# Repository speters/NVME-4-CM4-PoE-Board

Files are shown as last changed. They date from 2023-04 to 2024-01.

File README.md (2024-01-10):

# CM4-IO-POE-4G PCIEx1 to NVME Adapter

This is an NVME (M-key) adapter board for the PCIEx1 slot.

Its PCB is designed with a break-away section for the fingered connector. This is then soldered in a matching slot of the PCB to form a 90 degree connector.

## Revisions

 * 0.9.0 added oscillator for 32.768kHz SUSClk signal

 * 0.8.2 finger board improvements, minor size adjustments

 * 0.8.1 working version, gone into small production run

## Description

PCB of the 0.8.2 version without SUSClk
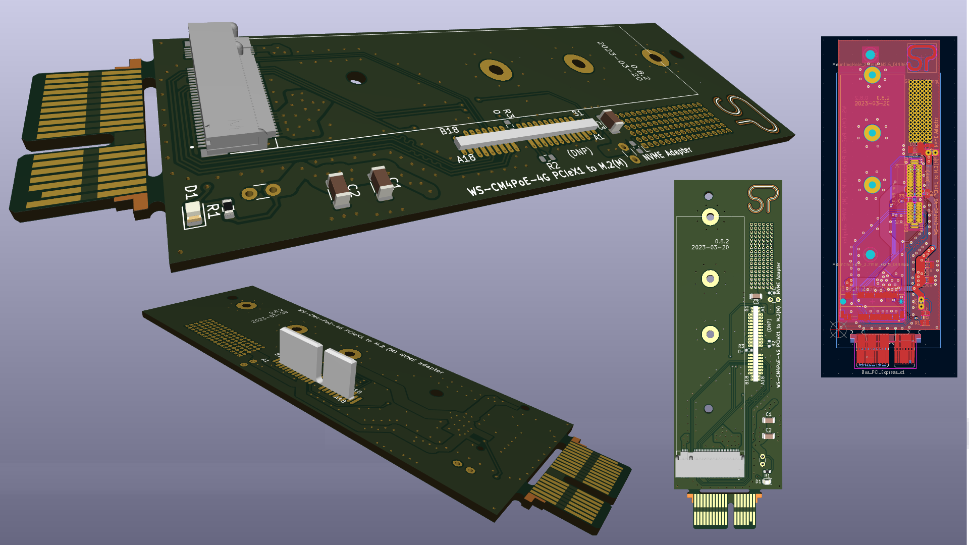
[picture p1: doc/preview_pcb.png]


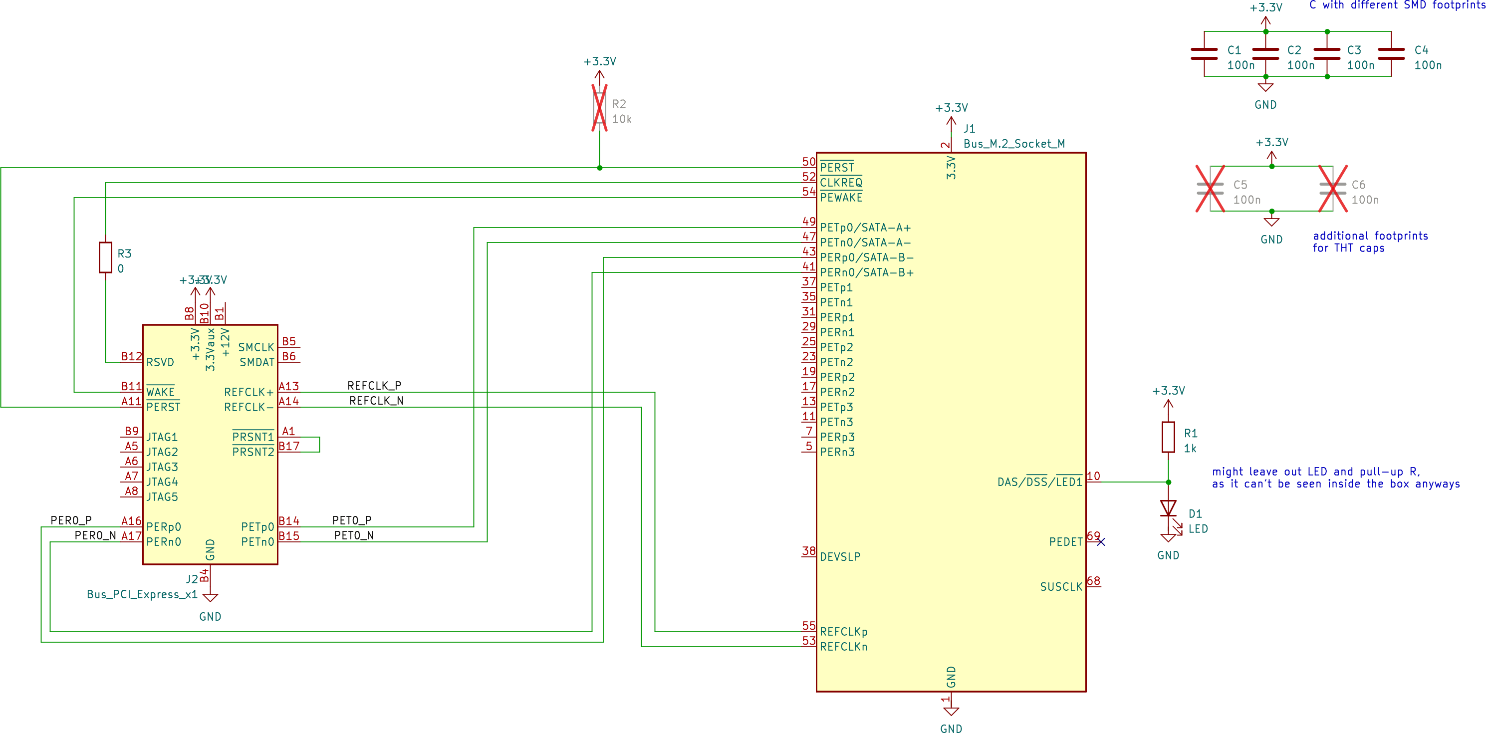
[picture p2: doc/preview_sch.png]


It is designed to fit the [Waveshare CM4G-IO-POE-4G-BOX](https://www.waveshare.com/wiki/Compute_Module_4_PoE_4G_Board#Isolation_GPIO.2FI2C).

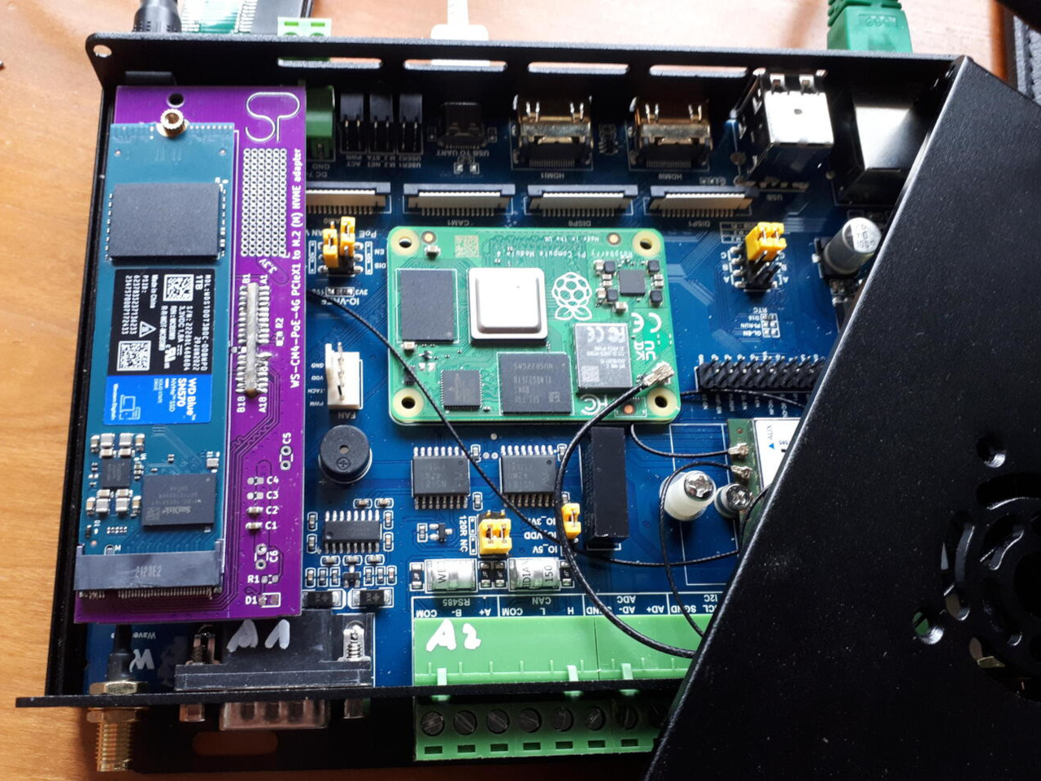
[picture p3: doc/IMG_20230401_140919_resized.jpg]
adapter in use


## Building

The PCB is cost-optimized to be produced by services like JLCPCB.

You have to separate the finger board from the PCB and solder it into its slot.
Make sure the finger board is at right angles to the main PCB when soldering.

An NVME M-key connector, a standoff, and screw for mounting the NVME has to be provided.
It is recommended to fix the board to the CM4 board with standoffs, not rely solely on the PCIEx1 connector to hold everything in place. For doing this, there are two holes matching holes in the baseboard PCB.

The adapter seems to work fine on the CM4 board without fitting the passives (capacitors and LED).

Remember that your kernel needs PCIe support. There is a convenient [docker cross-compile environment by Jeff Geerling](https://github.com/geerlingguy/raspberry-pi-pcie-devices/tree/master/extras/cross-compile).

## Improvement ideas

 * choose gold fingers for production (I went as cheap as possible with HASL)

 * get out of the way for the CAM0 FPC cable

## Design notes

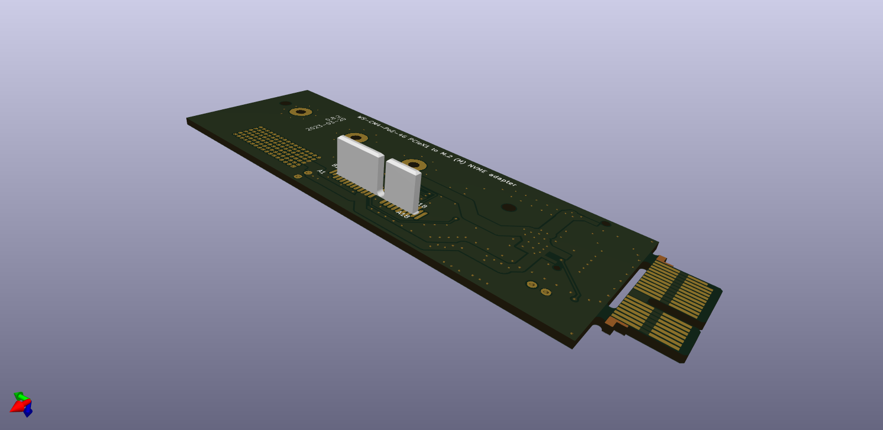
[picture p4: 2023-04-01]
doc/preview_pcb4.png

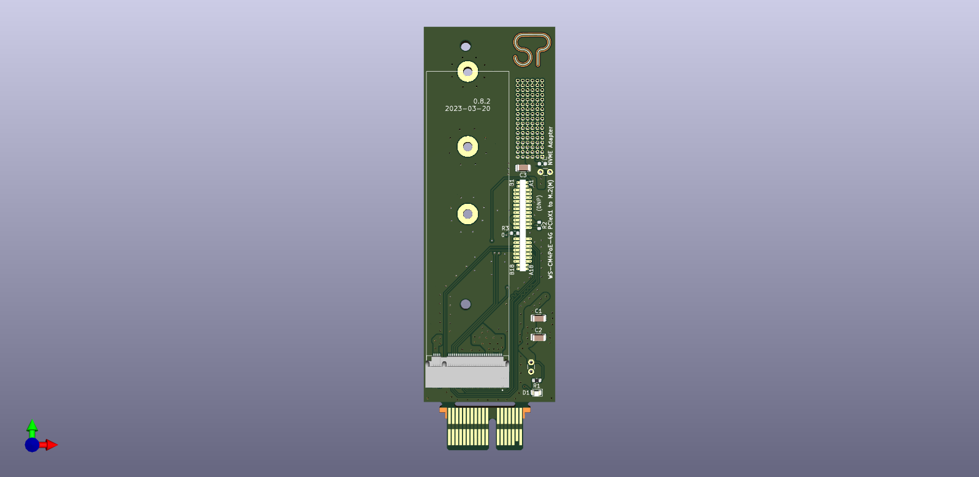
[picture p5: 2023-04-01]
doc/preview_pcb2.png

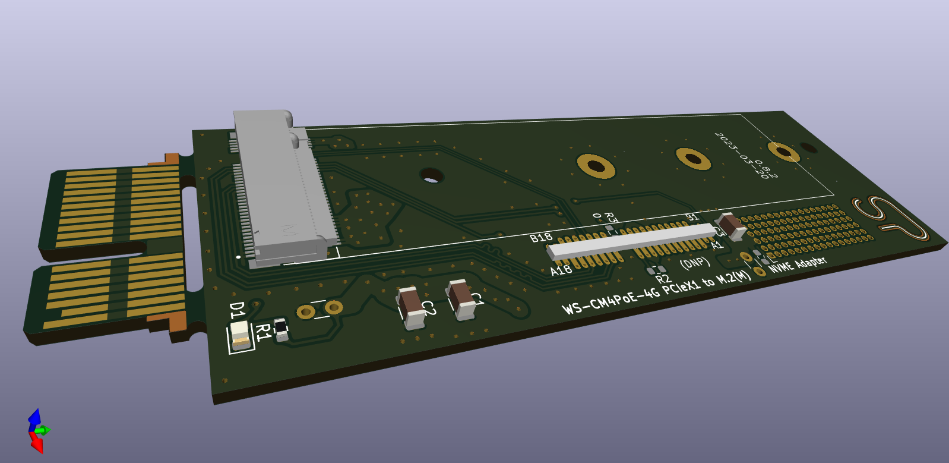
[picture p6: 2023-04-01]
doc/preview_pcb1.png

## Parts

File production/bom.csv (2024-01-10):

Designator | Footprint | Quantity | Value | LCSC Part #
C1 | 1206 | 1 | 100n
C2 | 1206 | 1 | 100n
C3 | 1206 | 1 | 100n
C4 | 0603 | 1 | 100n
C5, C6 | C_Disc_D3.0mm_W1.6mm_P2.50mm | 2 | 100n
C7 | 1206 | 1 | 100n
D1 | 0805 | 1 | LED
J1 | TE_1-2199230-6 M2 2280 | 1 | Bus_M.2_Socket_M
J2 | BUS_PCIexpress_x1 hor_1 | 1 | Bus_PCI_Express_x1
J3 | BUS_PCIexpress_x1 | 1 | Bus_PCI_Express_x1
J4 | BUS_PCIexpress_x1 SOLDER | 1 | Bus_PCI_Express_x1
J5 | proto112 127 | 1 | PROTO6x17
R1 | 0603 | 1 | 1k
R2 | 0603 | 1 | 10k
R3 | 0603 | 1 | 0
X1 | Oscillator_SMD_EuroQuartz_XO32-4Pin_3.2x2.5mm | 1 | 32.768kHz

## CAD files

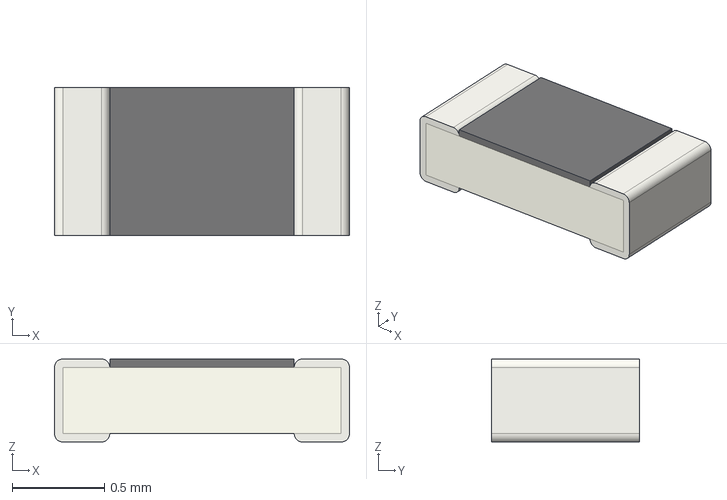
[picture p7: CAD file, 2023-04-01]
3d/R_0603_1608Metric.step
1.60 x 0.8 x 0.45 mm

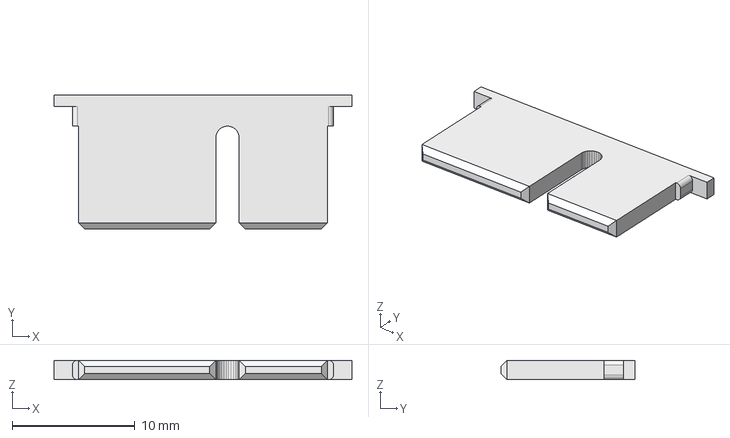
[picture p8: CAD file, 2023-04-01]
fingerconn.FCStd
24.3 x 10.9 x 1.58 mm

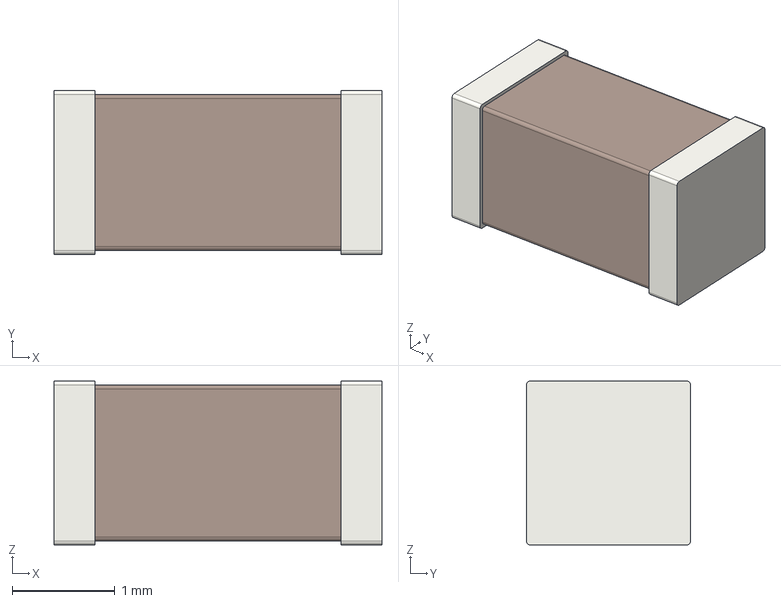
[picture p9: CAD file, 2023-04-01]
3d/C_1206_3216Metric.step
3.20 x 1.60 x 1.60 mm

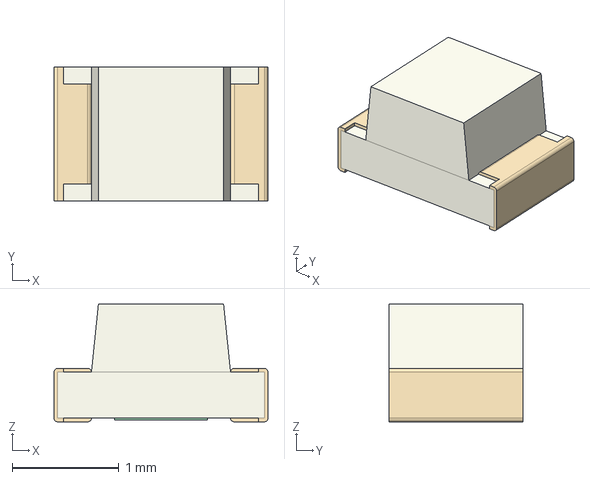
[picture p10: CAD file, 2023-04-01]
3d/LED_0805_2012Metric.step
2.00 x 1.25 x 1.10 mm

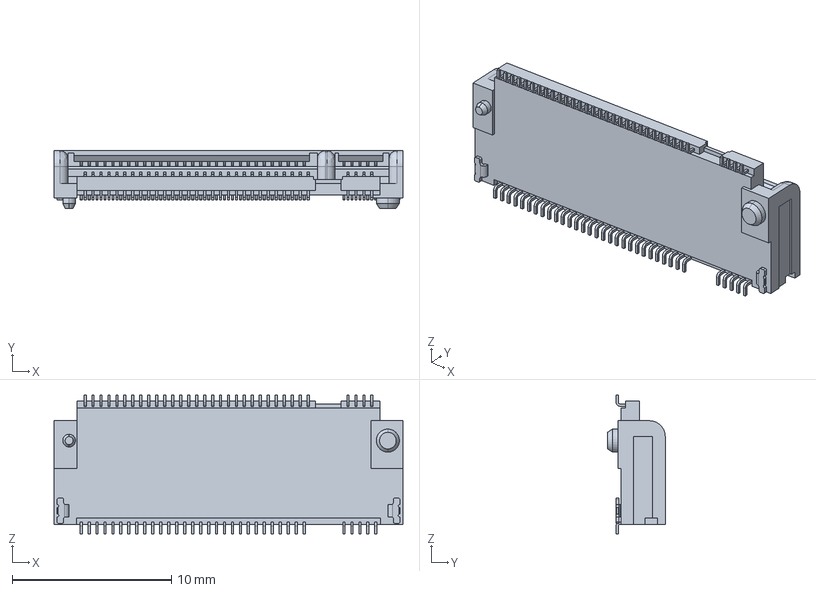
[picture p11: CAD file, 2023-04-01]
3d/c-1-2199119-3-c-3d.stp
21.9 x 3.62 x 8.70 mm

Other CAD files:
3d/fingerconn-fingerconn.step

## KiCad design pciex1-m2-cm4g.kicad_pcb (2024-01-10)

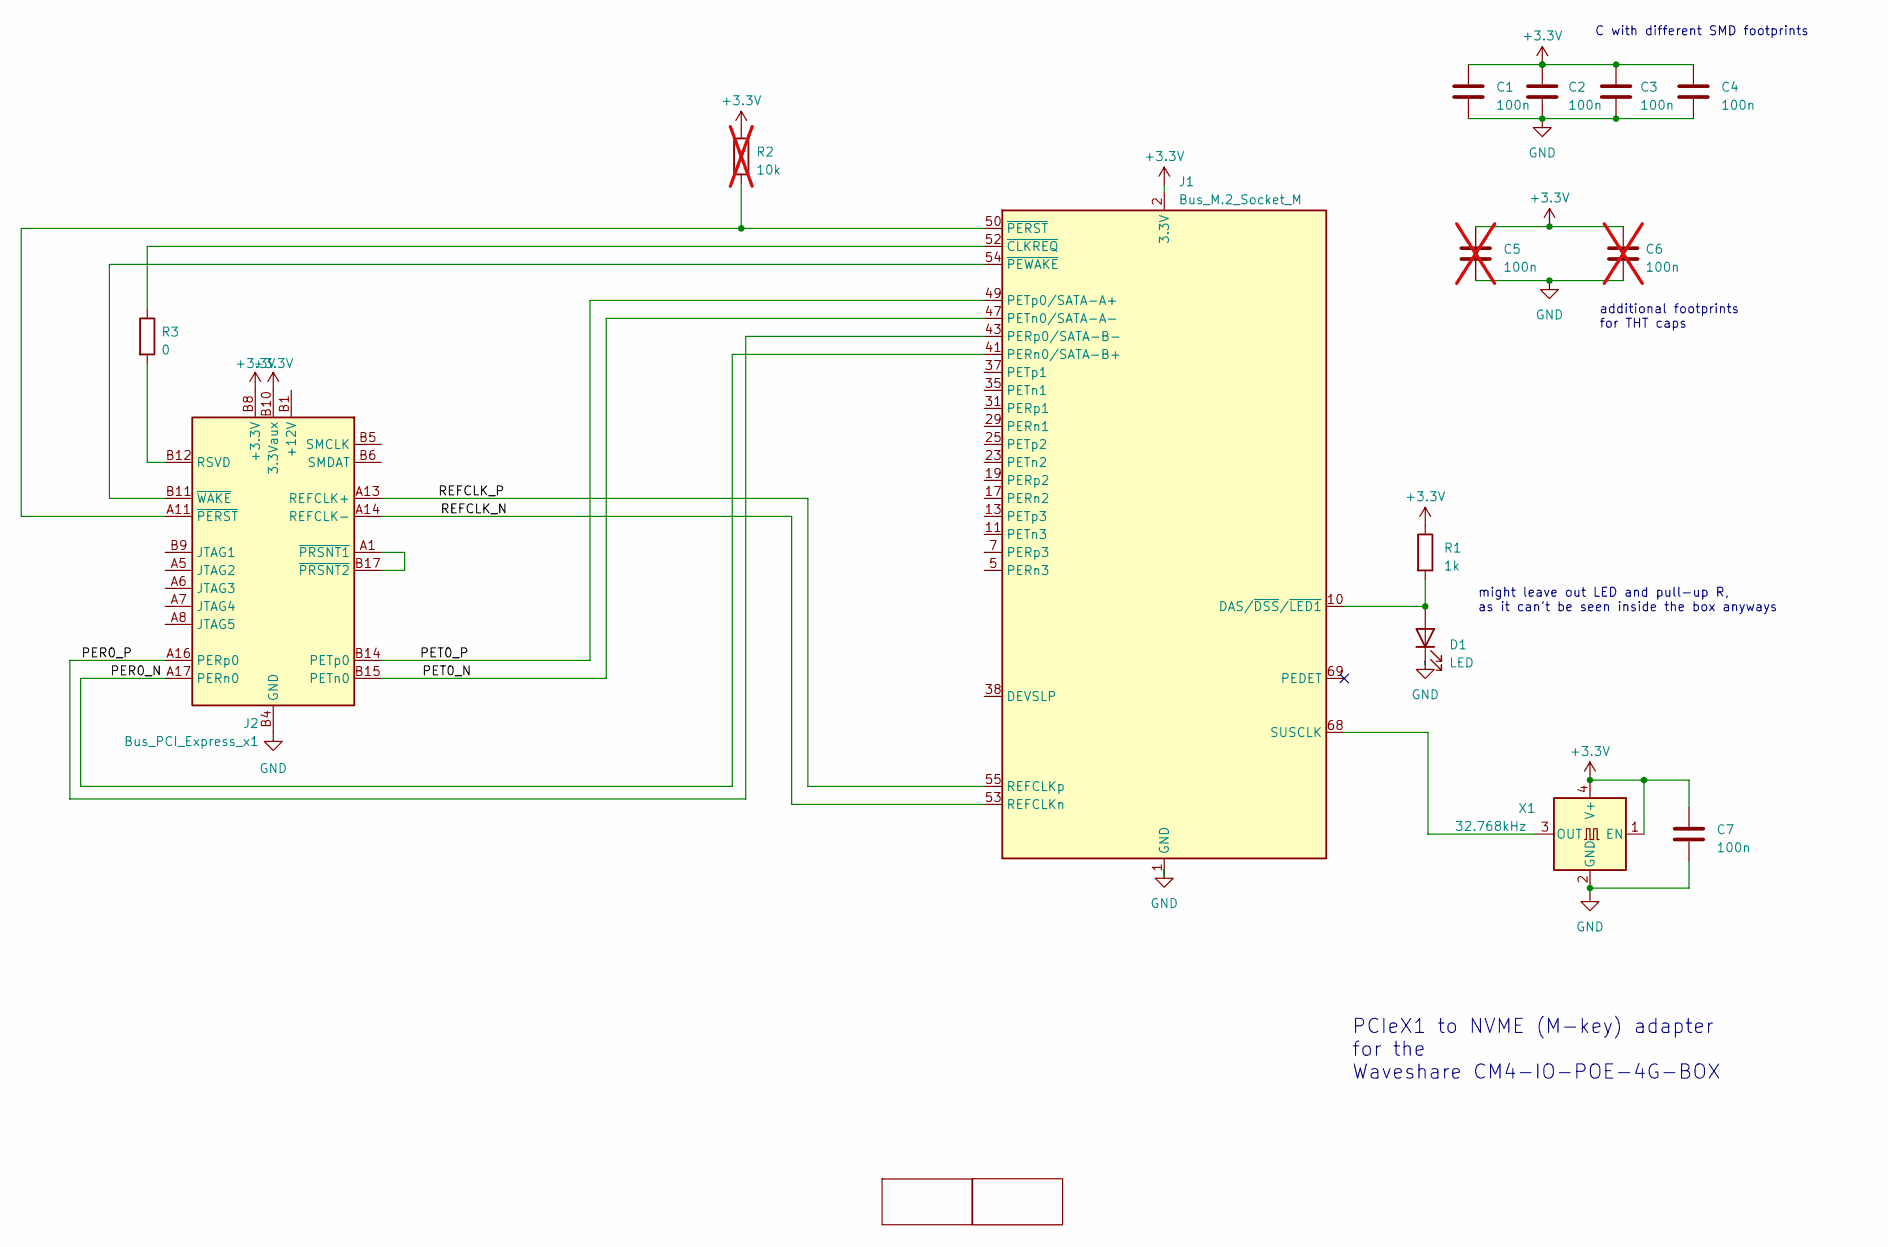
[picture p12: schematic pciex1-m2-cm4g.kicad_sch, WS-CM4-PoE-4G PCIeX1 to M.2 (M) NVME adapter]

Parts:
C1, C2, C3, C7: 100n; C_1206_3216Metric
C4: 100n; C_0603_1608Metric
C5, C6: 100n; C_Disc_D3.0mm_W1.6mm_P2.50mm; not fitted
D1: LED; LED_0805_2012Metric
J1: Bus_M.2_Socket_M; TE_1-2199230-6 M2 2280; PartGroup Card Edge Connectors; JLCPCB C841651
J2: Bus_PCI_Express_x1; BUS_PCIexpress_x1 hor_1
R1: 1k; R_0603_1608Metric
R2: 10k; R_0603_1608Metric; not fitted
R3: 0; R_0603_1608Metric
X1: 32.768kHz; Oscillator_SMD_EuroQuartz_XO32-4Pin_3.2x2.5mm; JLCPCB C2901582

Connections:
+3.3V: C1.1, C2.1, C3.1, C4.1, C5.1, C6.1, C7.1, J1.2 (3.3V), J1.4 (3.3V), J1.12 (3.3V), J1.14 (3.3V), J1.16 (3.3V), J1.18 (3.3V), J1.70 (3.3V), J1.72 (3.3V), J1.74 (3.3V), J2.A9 (+3.3V), J2.A10 (+3.3V), J2.B8 (+3.3V), J2.B10 (3.3Vaux), R1.1, R2.1, X1.1 (EN), X1.4 (V+); also elsewhere on the board
/PER0_N: J1.41 (PERn0/SATA-B+), J2.A17 (PERn0)
/PER0_P: J1.43 (PERp0/SATA-B-), J2.A16 (PERp0)
/PET0_N: J1.47 (PETn0/SATA-A-), J2.B15 (PETn0)
/PET0_P: J1.49 (PETp0/SATA-A+), J2.B14 (PETp0)
/REFCLK_N: J1.53 (REFCLKn), J2.A14 (REFCLK-)
/REFCLK_P: J1.55 (REFCLKp), J2.A13 (REFCLK+)
GND: C1.2, C2.2, C3.2, C4.2, C5.2, C6.2, C7.2, D1.1 (K), J1.1 (GND), J1.3 (GND), J1.9 (GND), J1.15 (GND), J1.21 (GND), J1.27 (GND), J1.33 (GND), J1.39 (GND), J1.45 (GND), J1.51 (GND), J1.57 (GND), J1.71 (GND), J1.73 (GND), J1.75 (GND), J2.A4 (GND), J2.A12 (GND), J2.A15 (GND), J2.A18 (GND), J2.B4 (GND), J2.B7 (GND), J2.B13 (GND), J2.B16 (GND), J2.B18 (GND), X1.2 (GND); also elsewhere on the board
unnamed: D1.2 (A), J1.10 (DAS/~DSS/~LED1), R1.2
unnamed: J1.68 (SUSCLK), X1.3 (OUT)
unnamed: J1.52 (~CLKREQ), R3.1
unnamed: J1.50 (~PERST), J2.A11 (~PERST), R2.2
unnamed: J1.54 (~PEWAKE), J2.B11 (~WAKE)
unnamed: J2.A2 (+12V), J2.A3 (+12V), J2.B1 (+12V), J2.B2 (+12V), J2.B3 (+12V)
unnamed: J2.B12 (RSVD), R3.2
unnamed: J2.A1 (~PRSNT1), J2.B17 (~PRSNT2)

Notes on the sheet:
C with different SMD footprints
PCIeX1 to NVME (M-key) adapter for the Waveshare CM4-IO-POE-4G-BOX
additional footprints for THT caps
might leave out LED and pull-up R, as it can't be seen inside the box anyways

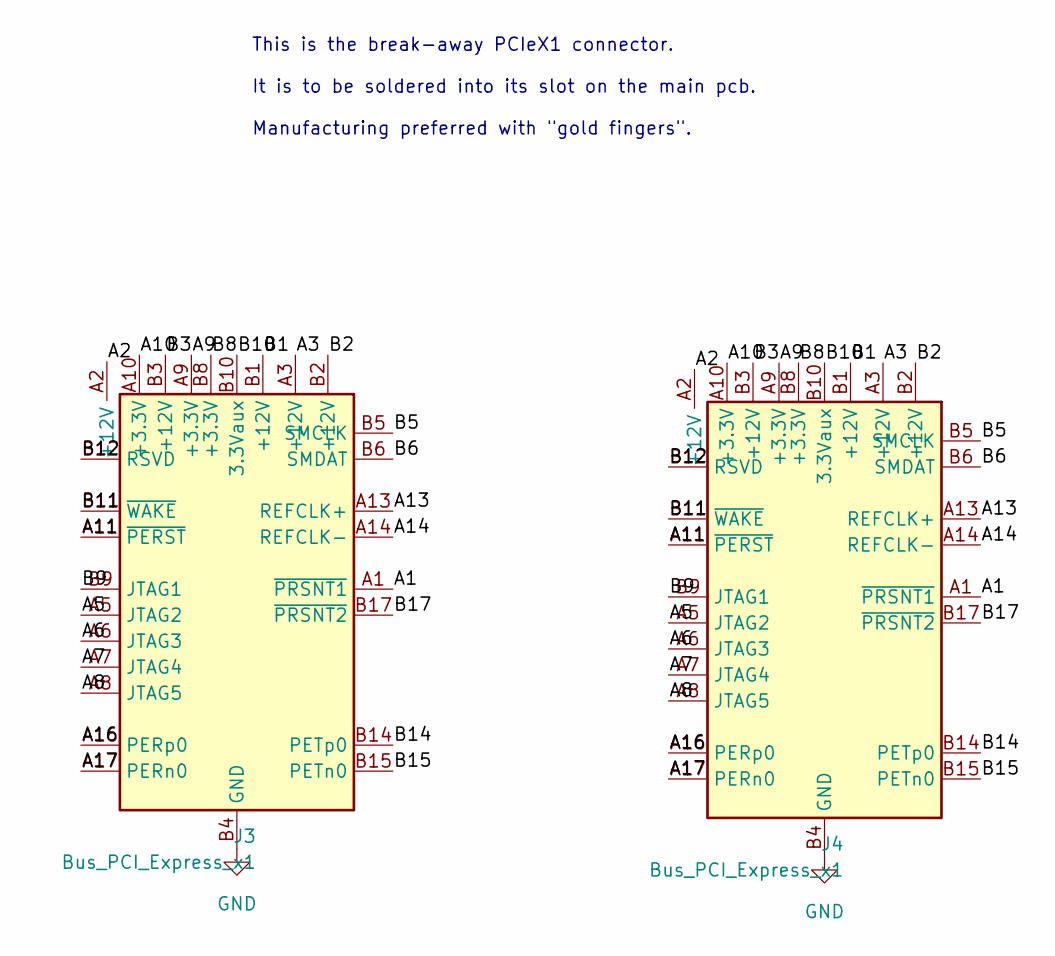
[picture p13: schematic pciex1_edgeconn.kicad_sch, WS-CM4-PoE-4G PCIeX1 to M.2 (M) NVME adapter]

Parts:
J3: Bus_PCI_Express_x1; BUS_PCIexpress_x1
J4: Bus_PCI_Express_x1; BUS_PCIexpress_x1 SOLDER

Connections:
/pciex1_edgeconn/A1: J3.A1 (~PRSNT1), J4.A1 (~PRSNT1)
/pciex1_edgeconn/A2: J3.A2 (+12V), J4.A2 (+12V)
/pciex1_edgeconn/A3: J3.A3 (+12V), J4.A3 (+12V)
/pciex1_edgeconn/A5: J3.A5 (JTAG2), J4.A5 (JTAG2)
/pciex1_edgeconn/A6: J3.A6 (JTAG3), J4.A6 (JTAG3)
/pciex1_edgeconn/A7: J3.A7 (JTAG4), J4.A7 (JTAG4)
/pciex1_edgeconn/A8: J3.A8 (JTAG5), J4.A8 (JTAG5)
/pciex1_edgeconn/A9: J3.A9 (+3.3V), J4.A9 (+3.3V)
/pciex1_edgeconn/A10: J3.A10 (+3.3V), J4.A10 (+3.3V)
/pciex1_edgeconn/A11: J3.A11 (~PERST), J4.A11 (~PERST)
/pciex1_edgeconn/A13: J3.A13 (REFCLK+), J4.A13 (REFCLK+)
/pciex1_edgeconn/A14: J3.A14 (REFCLK-), J4.A14 (REFCLK-)
/pciex1_edgeconn/A16: J3.A16 (PERp0), J4.A16 (PERp0)
/pciex1_edgeconn/A17: J3.A17 (PERn0), J4.A17 (PERn0)
/pciex1_edgeconn/B1: J3.B1 (+12V), J4.B1 (+12V)
/pciex1_edgeconn/B2: J3.B2 (+12V), J4.B2 (+12V)
/pciex1_edgeconn/B3: J3.B3 (+12V), J4.B3 (+12V)
/pciex1_edgeconn/B5: J3.B5 (SMCLK), J4.B5 (SMCLK)
/pciex1_edgeconn/B6: J3.B6 (SMDAT), J4.B6 (SMDAT)
/pciex1_edgeconn/B8: J3.B8 (+3.3V), J4.B8 (+3.3V)
/pciex1_edgeconn/B9: J3.B9 (JTAG1), J4.B9 (JTAG1)
/pciex1_edgeconn/B10: J3.B10 (3.3Vaux), J4.B10 (3.3Vaux)
/pciex1_edgeconn/B11: J3.B11 (~WAKE), J4.B11 (~WAKE)
/pciex1_edgeconn/B12: J3.B12 (RSVD), J4.B12 (RSVD)
/pciex1_edgeconn/B14: J3.B14 (PETp0), J4.B14 (PETp0)
/pciex1_edgeconn/B15: J3.B15 (PETn0), J4.B15 (PETn0)
/pciex1_edgeconn/B17: J3.B17 (~PRSNT2), J4.B17 (~PRSNT2)
GND: J3.A4 (GND), J3.A12 (GND), J3.A15 (GND), J3.A18 (GND), J3.B4 (GND), J3.B7 (GND), J3.B13 (GND), J3.B16 (GND), J3.B18 (GND), J4.A4 (GND), J4.A12 (GND), J4.A15 (GND), J4.A18 (GND), J4.B4 (GND), J4.B7 (GND), J4.B13 (GND), J4.B16 (GND), J4.B18 (GND); also elsewhere on the board

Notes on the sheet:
This is the break-away PCIeX1 connector. It is to be soldered into its slot on the main pcb. Manufacturing preferred with "gold fingers".

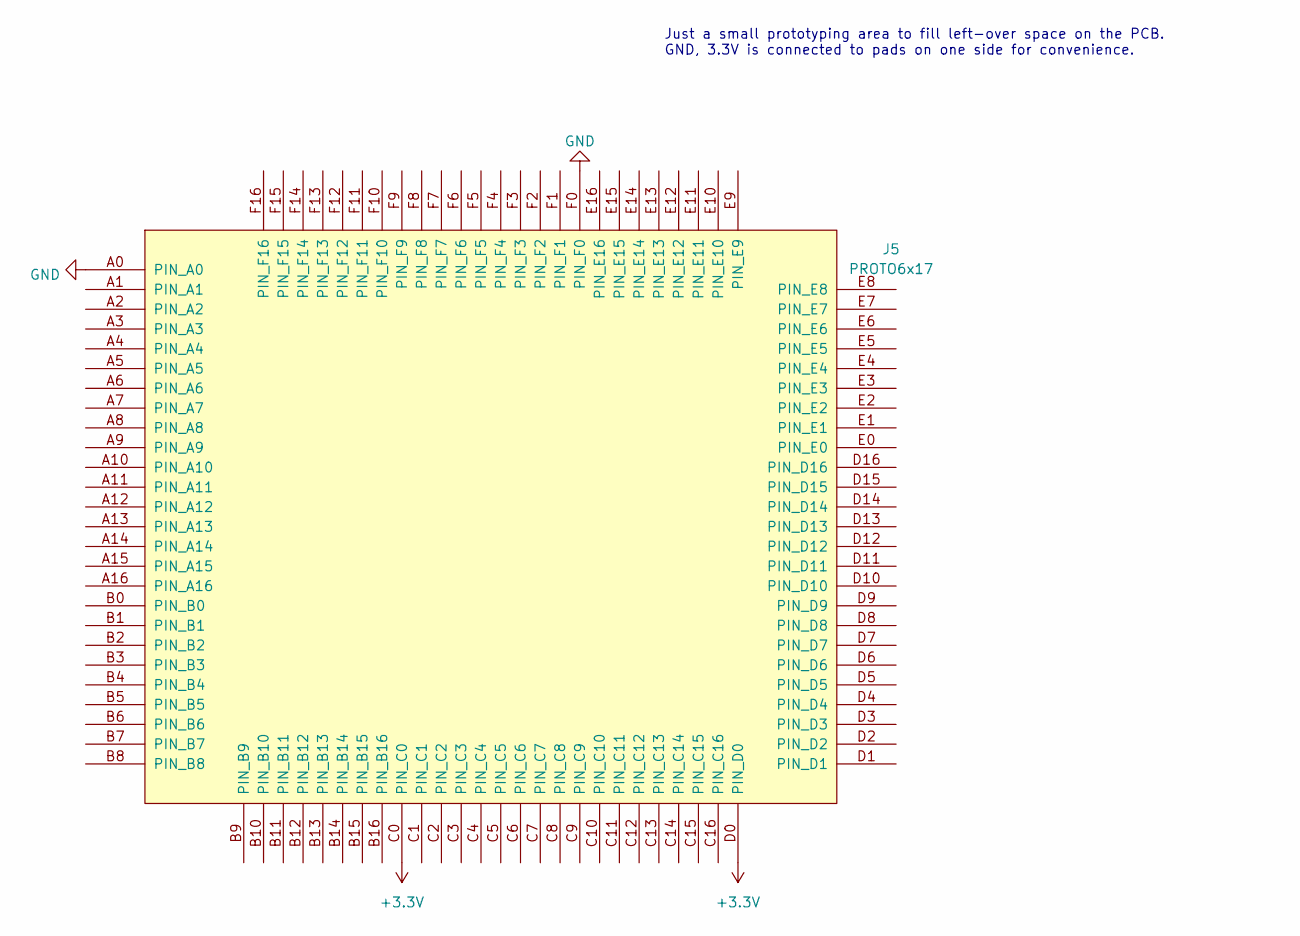
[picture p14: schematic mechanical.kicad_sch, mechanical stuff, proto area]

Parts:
J5: PROTO6x17; proto112 127

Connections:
+3.3V: J5.C0 (PIN), J5.D0 (PIN); also elsewhere on the board
GND: J5.A0 (PIN), J5.F0 (PIN); also elsewhere on the board

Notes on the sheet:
Just a small prototyping area to fill left-over space on the PCB. GND, 3.3V is connected to pads on one side for convenience.

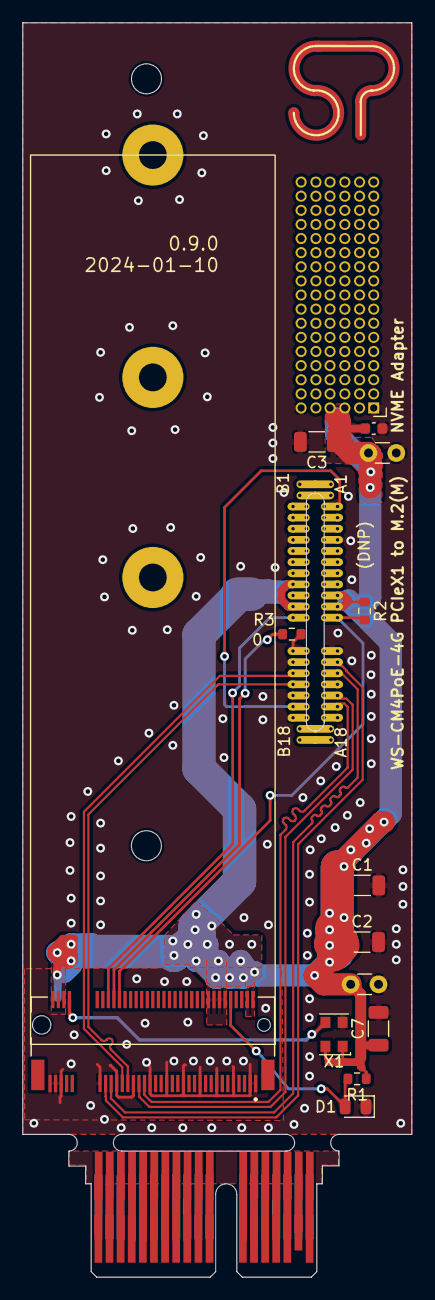
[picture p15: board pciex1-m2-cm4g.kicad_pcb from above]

Board: 2 copper layers, 35.0 x 112.8 mm, 20 parts (0 on the bottom side), 43 nets.

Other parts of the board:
Hole1, Hole2: MountingHole_2.7mm_M2.5_DIN965
Logo: SP_Logo_10mm

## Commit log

2023-04-01 initial import
    [C_1206_3216Metric.step, LED_0805_2012Metric.step, R_0603_1608Metric.step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]
2023-04-01 pictures of pcb and photo
2023-04-01 pcb preview image
2023-04-01 added schematic preview
2023-04-01 soldering tip
2023-04-03 standoff holes mentioned
2024-01-10 added SUSClk
    [bom.csv, designators.csv, mechanical.kicad_sch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]

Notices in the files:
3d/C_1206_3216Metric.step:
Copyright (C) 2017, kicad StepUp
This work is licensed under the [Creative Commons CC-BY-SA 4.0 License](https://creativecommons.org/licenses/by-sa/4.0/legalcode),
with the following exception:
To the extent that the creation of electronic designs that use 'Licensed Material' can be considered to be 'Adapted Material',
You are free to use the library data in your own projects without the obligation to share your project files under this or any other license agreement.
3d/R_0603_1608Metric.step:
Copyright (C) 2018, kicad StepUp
